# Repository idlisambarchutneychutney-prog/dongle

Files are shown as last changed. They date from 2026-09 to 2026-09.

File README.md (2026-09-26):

# Dongle



A custom-designed, programmable USB dongle featuring a 9-LED grid, powered by the CH552G microcontroller. The board includes a user push-button and a USB connector.

## Features
* **Microcontroller:** CH552G 
* **Display:** 9x LEDs (D1-D9) with dedicated 330Ω resistors
* **Input:** 1x tactile push-button for user interaction
* **Custom Enclosure:** Includes a 3D-printable shell designed in Onshape

## Previews

### Schematic


### PCB Layout & Artwork



### case


## Bill of Materials (BOM)

| Designator | Component Name | Value/Specs | Footprint | LCSC Part # | Notes / Sourcing |
| :--- | :--- | :--- | :--- | :--- | :--- |
| **U1** | CH552G | 8-bit MCU, 16KB Flash | SOP-16 | `C111292` | Microcontroller |
| **C1, C2** | Ceramic Capacitor | 100nF (0.1uF) | 0603 | `C14663` | Decoupling Caps |
| **R1** | Resistor | 10kΩ | 0603 | `C25804` | Pull-up Resistor |
| **R2, R3, R4, R5, R6, R7, R8, R9, R10** | Resistor | 330Ω | 0603 | `C23138` | Current limiting for LEDs |
| **D1, D2, D3, D4, D5, D6, D7, D8, D9** | LED | Standard LED | 0805 | `C84256` | Indicator/Matrix LEDs |
| **J1** | USB Type-A Port | Male, 4-Pin, SMD | *See Footprint*| — | *Inventory Shortage* (Solder manually or substitute) |
| **SW1** | Tactile Switch | Push Button | *See Footprint*| — | *Inventory Shortage* (Solder manually or substitute) |

##  Manufacturing & Assembly
1. **PCB Fabrication:** Download the `.zip` file from the `/PCB` folder and upload it to your preferred PCB manufacturer. 
2. **Components:** All components are surface-mount (SMD) and located on the top layer to preserve the artwork on the back.
3. **3D Printing:** The enclosure can be printed in PLA, PETG, or ABS without supports. Use the `.step` file provided to slice the model in your preferred slicer.

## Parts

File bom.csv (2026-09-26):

Reference | Qty | Value | Footprint | Description
C1,C2 | 2 | 100nF | Capacitor_SMD:C_0603_1608Metric | Unpolarized capacitor
D1,D2,D3,D4,D5,D6,D7,D8,D9 | 9 | LED | LED_SMD:LED_0805_2012Metric | Light emitting diode
J1 | 1 | USB_A | CH552G:USB-A | USB Type A connector
R1 | 1 | 10K | Resistor_SMD:R_0603_1608Metric | Resistor
R2,R3,R4,R5,R6,R7,R8,R9,R10 | 9 | 330R | Resistor_SMD:R_0603_1608Metric | Resistor
SW1 | 1 | SW_Push | Button_Switch_SMD:SW_SPST_TS-1088-xR020 | Push button switch, generic, two pins
U1 | 1 | CH552G | Package_SO:JEITA_SOIC-16_3.9x9.9mm_P1.27mm

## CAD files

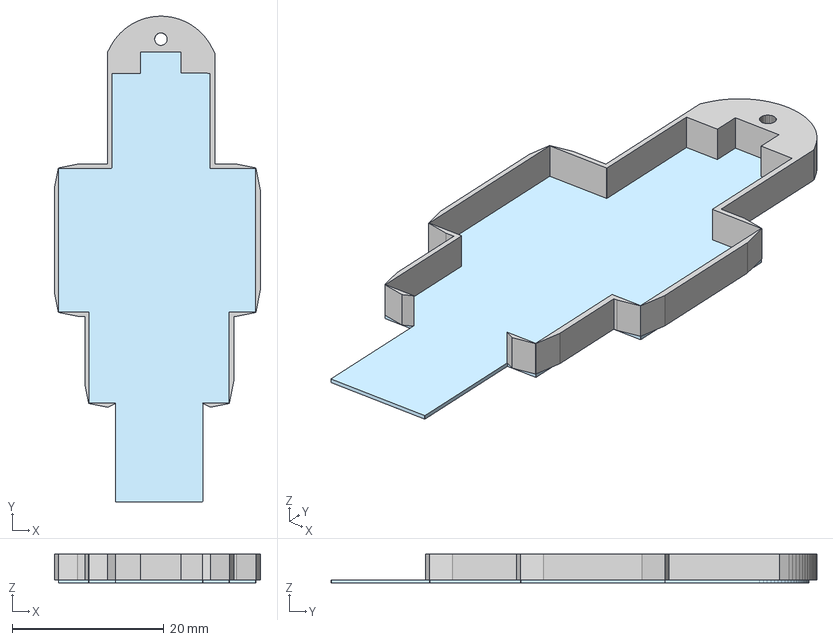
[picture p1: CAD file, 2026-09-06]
CAD/dongle_case.step
27.2 x 64.1 x 3.80 mm

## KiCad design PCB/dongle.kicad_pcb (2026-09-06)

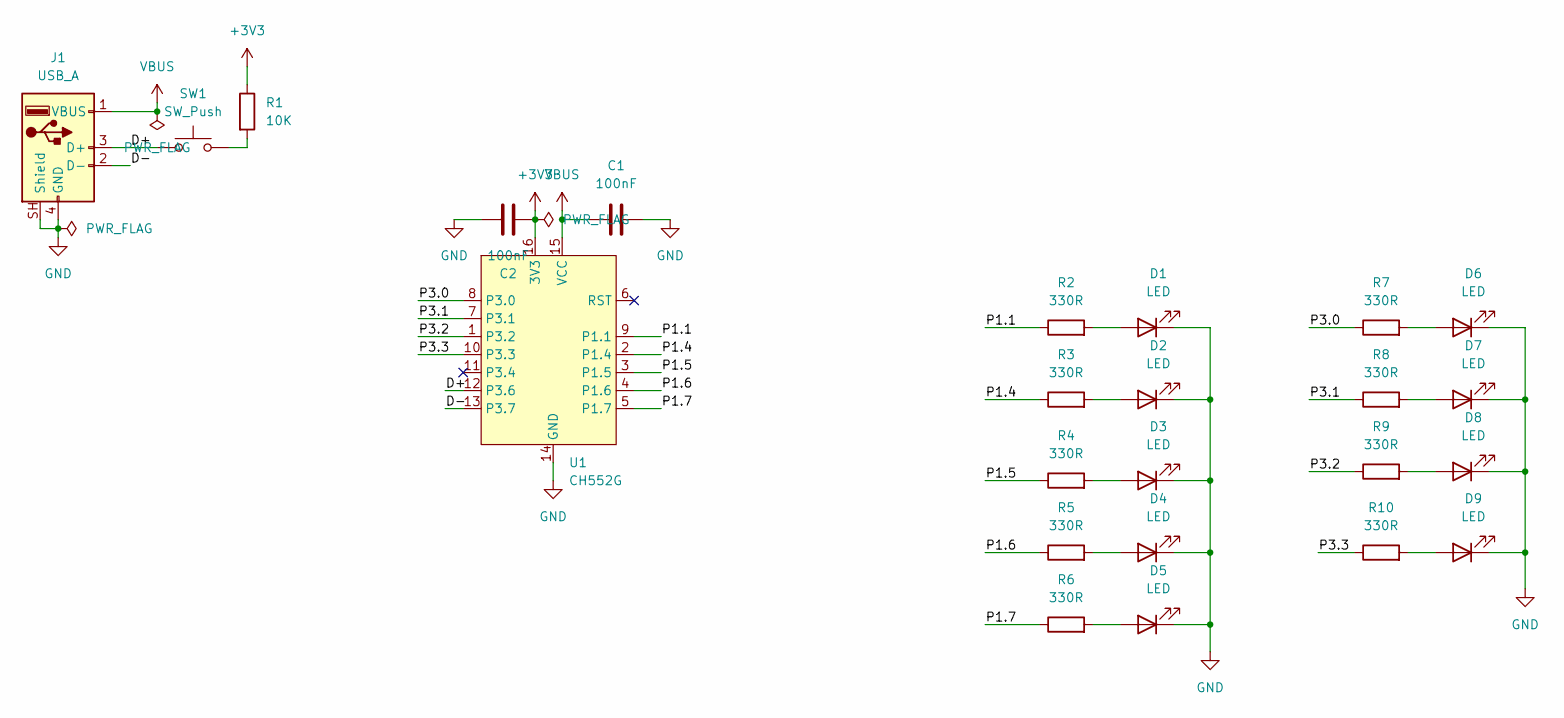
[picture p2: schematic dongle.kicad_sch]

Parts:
C1, C2: 100nF; C_0603_1608Metric
D1, D2, D3, D4, D5, D6, D7, D8, D9: LED; LED_0805_2012Metric
J1: USB_A; USB-A
R1: 10K; R_0603_1608Metric
R2, R3, R4, R5, R6, R7, R8, R9, R10: 330R; R_0603_1608Metric
SW1: SW_Push; SW_SPST_TS-1088-xR020
U1: CH552G; JEITA_SOIC-16_3.9x9.9mm_P1.27mm

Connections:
+3V3: C2.1, R1.1, U1.16 (3V3)
/D+: J1.3 (D+), SW1.1, U1.12 (P3.6)
/D-: J1.2 (D-), U1.13 (P3.7)
/P1.1: R2.1, U1.9 (P1.1)
/P1.4: R3.1, U1.2 (P1.4)
/P1.5: R4.1, U1.3 (P1.5)
/P1.6: R5.1, U1.4 (P1.6)
/P1.7: R6.1, U1.5 (P1.7)
/P3.0: R7.1, U1.8 (P3.0)
/P3.1: R8.1, U1.7 (P3.1)
/P3.2: R9.1, U1.1 (P3.2)
/P3.3: R10.1, U1.10 (P3.3)
GND: C1.2, C2.2, D1.1 (K), D2.1 (K), D3.1 (K), D4.1 (K), D5.1 (K), D6.1 (K), D7.1 (K), D8.1 (K), D9.1 (K), J1.4 (GND), J1.SH (Shield), U1.14 (GND)
unnamed: D1.2 (A), R2.2
unnamed: D2.2 (A), R3.2
unnamed: D3.2 (A), R4.2
unnamed: D4.2 (A), R5.2
unnamed: D5.2 (A), R6.2
unnamed: D6.2 (A), R7.2
unnamed: D7.2 (A), R8.2
unnamed: D8.2 (A), R9.2
unnamed: D9.2 (A), R10.2
unnamed: R1.2, SW1.2
VBUS: C1.1, J1.1 (VBUS), U1.15 (VCC)

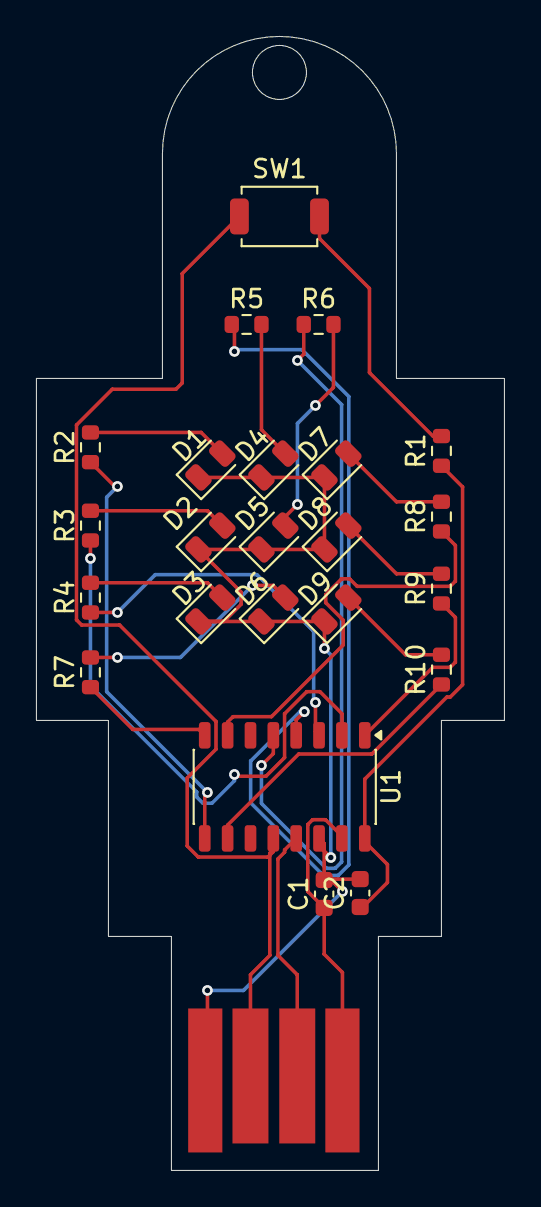
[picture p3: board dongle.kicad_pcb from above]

Board: 2 copper layers, 26.0 x 63.0 mm, 24 parts (0 on the bottom side), 24 nets.
